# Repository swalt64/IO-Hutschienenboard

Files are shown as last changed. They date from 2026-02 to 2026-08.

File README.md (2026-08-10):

# IO-Hutschienenboard

ESP32-S3 basierter 12-Kanal-I/O-Hutschienencontroller mit Web-UI, OLED-Display und Android-App.

Aktuelle Firmware-Version: siehe `IO-Hutschienenboard_SRC/include/version.h` (wird bei jedem Upload automatisch hochgezählt).

## Hardware

Zwei-Platinen-Aufbau (Base Board + Top Board) mit ESP32-S3-WROOM-1 (N16R8, DUBEUYEW 44-pin DIL-Modul, Versorgung direkt über 3V3).

**Base Board:**
- **12× S0-Eingänge** — galvanisch getrennt (SL4U-1205 DC/DC), 6× ILD213T Optokoppler, 2× SN74HCT14DR Schmitt-Trigger; unterstützt DC-Kontakte und 8VAC-Erkennung
- **12× Relaisausgänge** — Panasonic DSP1A-L2-DC12V, **bistabil mit zwei Spulen**; angesteuert über **zwei** MCP23017 (0x21 = SET-Spulen, 0x20 = RESET-Spulen) → ULN2803A-Treiber → Ferritperlen → Relaisspulen; Impulsdauer 20 ms
- **Versorgung** — 12V-Eingang, AP62200WU-7 Buck-Wandler → 3V3p; SL4U-1205 isolierter DC/DC → I-5Vp für die Optokoppler
- **Peripherie-Reset** — GPIO2 (aktiv-low) auf alle drei MCP23017
- **Steckverbinder** — J200/J201 (S0-Eingänge + I-GND), J202 (externe Buchse, normalerweise unbestückt: I2C, GPIO13/14, Reset, 12V, 3V3p), J300–J302 (Relaiskontakte)

**Top Board (über 14-poligen Board-to-Board-Stecker P101 → P1):**
- **OLED-Display 128×64** — JMD0.96-1 (SSD1306) an I2C 0x3C
- **5 Navigationstasten** — ENTER, UP, DOWN, LEFT, RIGHT an MCP23017 0x22, GPA0–GPA4 (aktiv-low), Interrupt via INTA → GPIO13
- **3 Status-LEDs** — WLAN (rot), OUTPUT (gelb), RUN (grün) an MCP23017 0x22, GPB0–GPB2
- **Reset-Taster** auf dem EN-Pin des ESP32

**I2C-Adressen:** 0x20 (Relais RESET), 0x21 (Relais SET), 0x22 (Top Board), 0x3C (OLED). Bus: SDA = GPIO11, SCL = GPIO12, 100 kHz.

## Projektstruktur

- `IO-Hutschienenboard_SRC/` PlatformIO-Projektwurzel
  - `src/main.cpp` Kernanwendung: WiFi, AsyncWebServer, WebSocket, Relaissteuerung, Eingangs-Flankenerkennung, Auto-Off-Timer, Kanalnamen, Tastennavigation, NVS-Persistenz
  - `src/display.cpp` OLED-Ausgabe (Adafruit SSD1306), Namespace `display::`
  - `src/statusled.cpp` WS2812-RGB-LED-Muster (non-blocking)
  - `src/swtools.cpp` Debug-Logging mit Kategorien, ANSI-Farben, NTP-Zeitstempel
  - `include/pin_config.h` GPIO-Mapping, MCP-Adressen, Relaistabellen
  - `data/` LittleFS-Web-Assets: `index.html` (Bedienung), `config.html` (Konfiguration), `mapping.html` (Eingang→Ausgang), `status.html` (Systemstatus), PWA-Manifest + Service Worker
  - `boards/` eigenes PlatformIO-Board-Profil (`esp32-s3-devkitc-1-n16r8`)
  - `scripts/` Build-Hooks (Versions-Bump, OTA-Passwort einlesen)
- `AndroidApp/` native Android-App (siehe [AndroidApp/README.md](AndroidApp/README.md))
- `HARDWARE/PCB/` Altium-Designdaten (Base Board + Top Board)
- `DOKU/` Dokumentation und LTspice-Simulationen

## Funktionen

**Bedienung und Netzwerk**
- AP-Modus (`IO-Hutschiene`, 192.168.50.1) mit DHCP, parallel optionaler STA-Modus mit gespeicherten Zugangsdaten
- mDNS-Hostname `HS-IO` (`hs-io.local`)
- Web-UI mit WebSocket-Live-Updates, HTTP-Basic-Auth auf allen Seiten, der REST-API und dem WebSocket (Default `admin`/`admin`, in der UI änderbar)
- REST-API: `GET /api/state` (Gesamtzustand als JSON, inkl. `wifi_rssi`, `wifi_bssid`, `wifi_channel`), `GET /api/cmd` (`toggle`, `set`, `alloff`)
- Verbindet sich beim Start mit dem **stärksten** Access Point der SSID (relevant bei Repeater/Mesh mit gleicher SSID)
- PWA-fähig (Manifest + Service Worker), Android-App über dasselbe WebSocket-Protokoll

**Ausgänge**
- Auto-Off-Timer je Kanal mit Live-Countdown in Web-UI und Display
- Betriebsart je Ausgang: Toggle oder Taster
- Kanäle einzeln aktivierbar, frei sortierbar (Anzeigereihenfolge)
- Fernsteuer-Schutz je Ausgang: geschützte Kanäle schalten nur mit gesetztem `armed`-Flag
- „Alles aus" per Langdruck (2 s) auf einen Eingangs-Taster, über die Web-UI oder per langem Tastendruck in der App
- **Je Ausgang konfigurierbar, ob er bei „Alles aus" mitgeschaltet wird** — Spalte „Alles aus" in der Konfigurationsseite. Damit lassen sich Verbraucher wie eine Klimaanlage von der Sammelabschaltung ausnehmen; sie bleiben dann an, egal ob die Abschaltung vom Taster, der Web-UI oder der App kommt. Standard: alle Ausgänge werden mitgeschaltet.

**Eingänge**
- Flankenerkennung im `loop()`, gemapptes Relais wird geschaltet
- Betriebsart je Eingang: Toggle oder Taster
- DC- und AC-Erkennung (50 Hz Rechteck)
- Eigene Namen je Eingang

**Vor-Ort-Bedienung**
- OLED zeigt Kanalnummer, Name, EIN/AUS und Restlaufzeit
- UP/DOWN blättert Kanäle, ENTER schaltet, LEFT/RIGHT ändert die Restlaufzeit um ±1 min (temporär, nicht in NVS)
- WLAN-LED signalisiert Verbindungszustand und Signalqualität über die Blinkrate (Dauerlicht ab RSSI ≥ 50 %)

**Persistenz**
- NVS via Preferences, Namespace `io-config`: `ssid`, `pass`, `ui_user`, `ui_pass`, `ota_pass`, `mm*` (Eingangs-Zuordnung als Bitmaske), `auto*`, `outmode*`, `inmode*`, `ord*`, `ena*`, `prot*`, `name*`, `iname*`
- Konfiguration in der Web-UI exportier- und importierbar (`load_config`), Werksreset über `reset_io`
- **Reset per Taste beim Booten** (je 5 s halten, Fortschritt auf dem OLED, Loslassen bricht ab):
  - **ENTER** → Web- und OTA-Passwort zurück auf `admin`/`admin`
  - **DOWN** → E/A-Werkseinstellung: Zuordnungen, Timer und Namen zurücksetzen

**Update**
- ElegantOTA über die Web-UI (`/update`, passwortgeschützt)
- ArduinoOTA über PlatformIO-Environment `esp32s3-ota` (Port 3232)

## Build und Flash

Aus `IO-Hutschienenboard_SRC/` ausführen:

```powershell
& "C:\Users\stwal\.platformio\penv\Scripts\platformio.exe" run
& "C:\Users\stwal\.platformio\penv\Scripts\platformio.exe" run -t upload
& "C:\Users\stwal\.platformio\penv\Scripts\platformio.exe" run -t uploadfs
```

Nach Änderungen an `data/` muss `uploadfs` ausgeführt werden, sonst bleibt die alte Web-UI im Flash.

Die Plattform ist in `platformio.ini` fest auf `espressif32@6.12.0` gepinnt. Der Pin ist notwendig — mit dem neueren Arduino-Core 3.x kompilieren die WS2812-Bibliothek und die DHCP-Abfrage in `main.cpp` nicht mehr.

### OTA-Upload über WLAN

```powershell
& "C:\Users\stwal\.platformio\penv\Scripts\platformio.exe" run -e esp32s3-ota -t upload
```

Das OTA-Passwort wird aus `ota_pass.txt` gelesen (gitignored, Fallback `admin`). Nach einer Passwortänderung in der Web-UI muss diese Datei auf dem Entwicklungsrechner aktualisiert werden. Die Ziel-IP steht als `upload_port` in `platformio.ini`.

## Serieller Monitor

`platformio.ini` ist auf Rohausgabe konfiguriert: `monitor_speed = 115200`, `monitor_port = COM10`, `monitor_raw = yes`.

```powershell
& "C:\Users\stwal\.platformio\penv\Scripts\platformio.exe" device monitor -e esp32s3
```

## Bibliotheken

`ESP Async WebServer` (mathieucarbou) · `ArduinoJson` · `Adafruit MCP23017` · `Adafruit SSD1306` + `Adafruit GFX` · `Freenove WS2812 Lib for ESP32` · `ElegantOTA`

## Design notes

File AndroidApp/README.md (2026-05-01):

# HS-IO Android App

Native Android-App fuer das IO-Hutschienenboard.

## Funktionen

- Hauptansicht zeigt nur die 12 Ausgaenge.
- Links je Ausgang eine LED fuer den aktuellen Ausgangszustand.
- Rechts je Ausgang ein Button.
- Hochformat: einspaltige Liste.
- Querformat: zweispaltiges Raster.
- Verbindet sich per WebSocket mit `/ws` des ESP32.
- Verwendet dieselben Kommandos wie die Webseite:
  - Toggle-Ausgang: `{"cmd":"toggle","ch":n}`
  - Taster-Ausgang: `{"cmd":"set","ch":n,"val":true/false}`
  - langer Druck auf Toggle-Button: `{"cmd":"alloff"}`

## Build

In Android Studio den Ordner `AndroidApp` oeffnen und `app` bauen.

Standardverbindung:

- Host: `hs-io.local`
- Benutzer: `admin`
- Passwort: `admin`

Die Werte koennen in der App ueber das Menue `Einstellungen` geaendert werden.

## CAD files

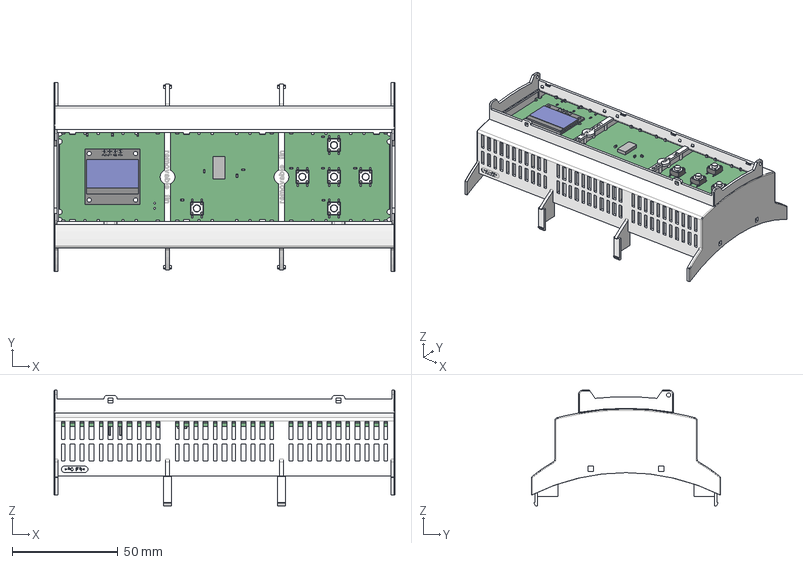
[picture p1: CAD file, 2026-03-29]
HARDWARE/PCB/3D-Objects/HS-IO TopBoard.step
161.6 x 89.7 x 54.9 mm
OLED-Disp
GPIO21HS-IO TopBoard
GPIO14HS-IO TopBoard
Extruded x 46
4301x20508x6 x 6
6100xx21121_PIN x 14
housing x 3
cover x 3
base-oa0 x 3
base x 3
Phoenix Geh㴳e BC 161,6 OT

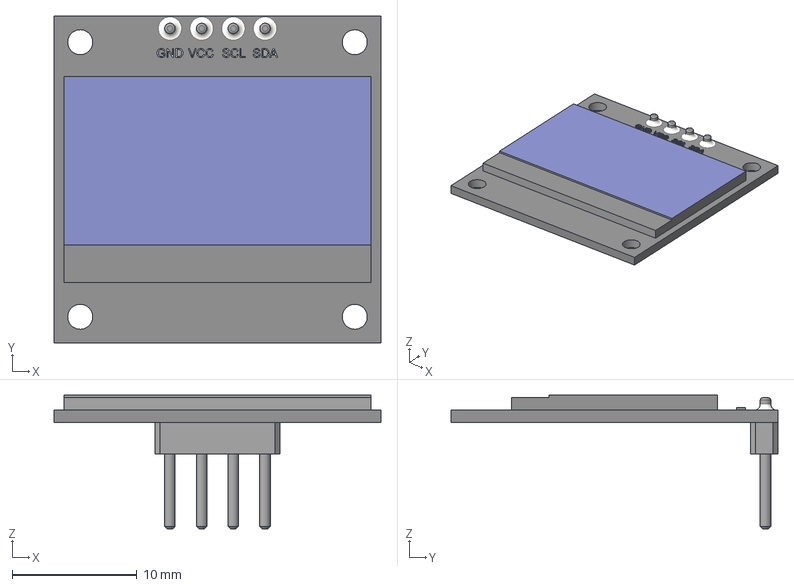
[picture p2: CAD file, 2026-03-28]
HARDWARE/PCB/3D-Objects/OLED-Disp.step
26.2 x 26.2 x 10.7 mm

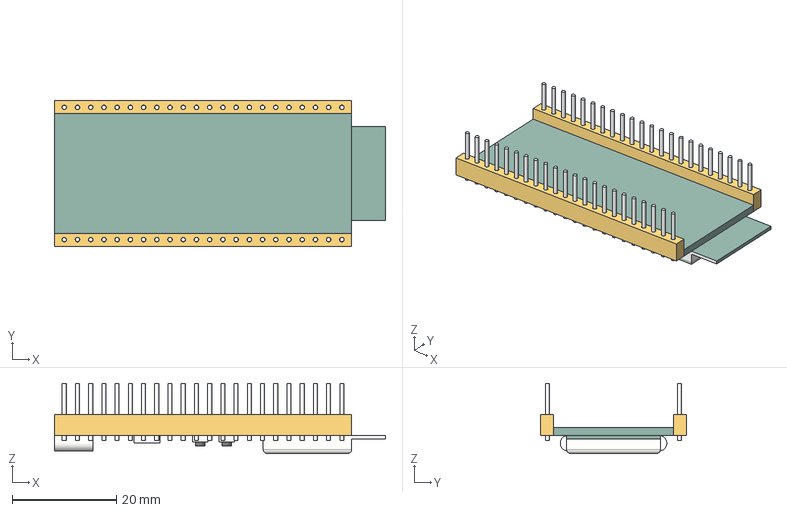
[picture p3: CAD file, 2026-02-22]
HARDWARE/PCB/3D-Objects/ESP32-S3-Board.step
63.6 x 28.1 x 13.5 mm

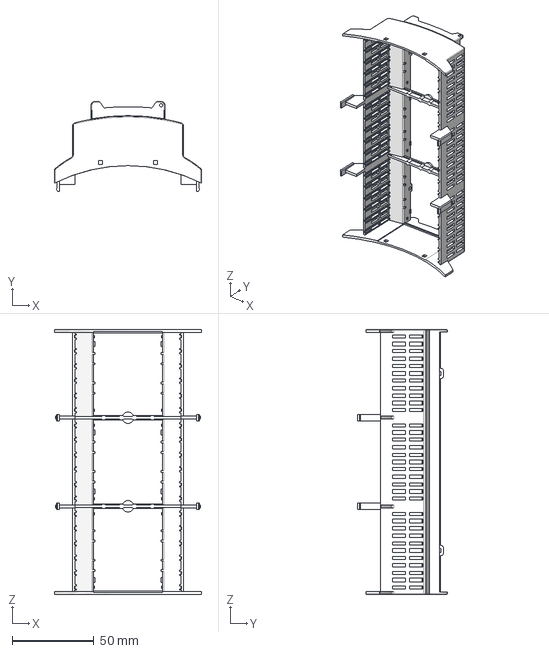
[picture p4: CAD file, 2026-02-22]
HARDWARE/PCB/3D-Objects/Phoenix Gehäuse BC 161,6 OT.step
89.7 x 54.9 x 161.6 mm

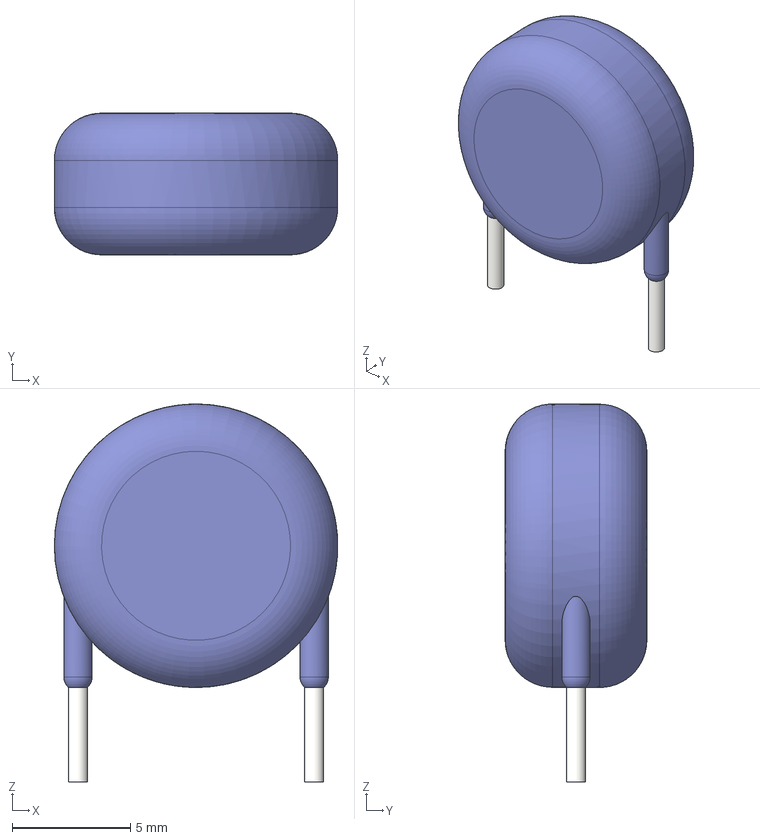
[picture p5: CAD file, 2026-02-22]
HARDWARE/PCB/3D-Objects/Y-Kondensator.step
12.0 x 6.00 x 16.0 mm

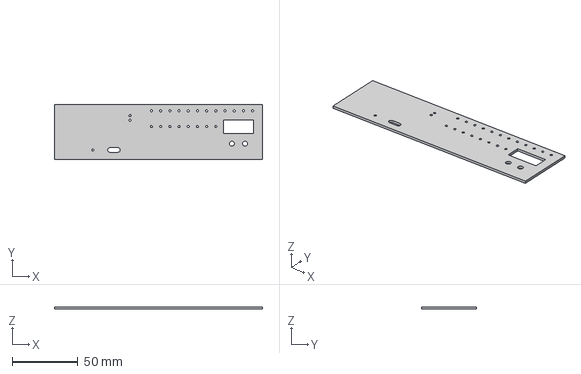
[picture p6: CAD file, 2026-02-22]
HARDWARE/PCB/3D-Objects/PQIO-Frontplatte.step
158.3 x 41.8 x 1.70 mm

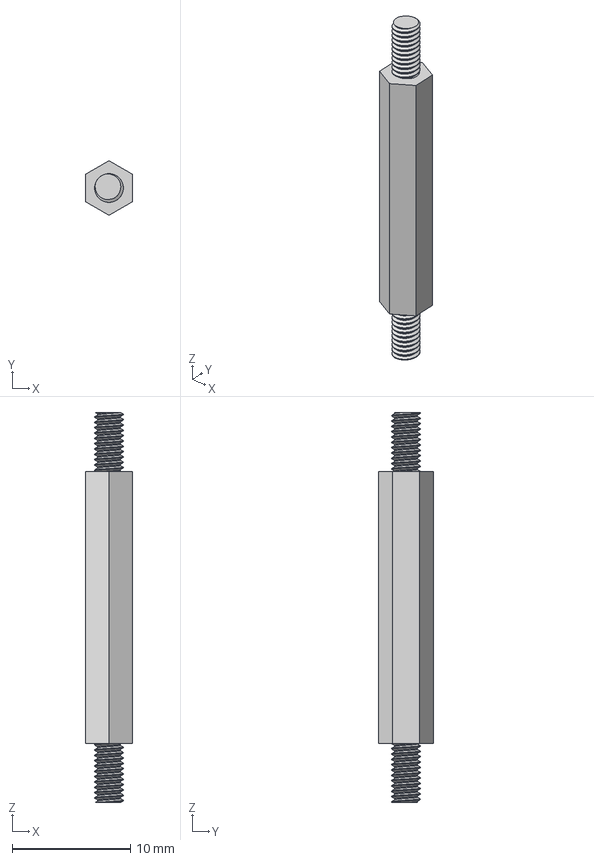
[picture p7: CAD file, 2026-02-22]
HARDWARE/PCB/3D-Objects/Distanzhalter M2.5 x 23 mm v1.step
4.00 x 4.62 x 33.0 mm

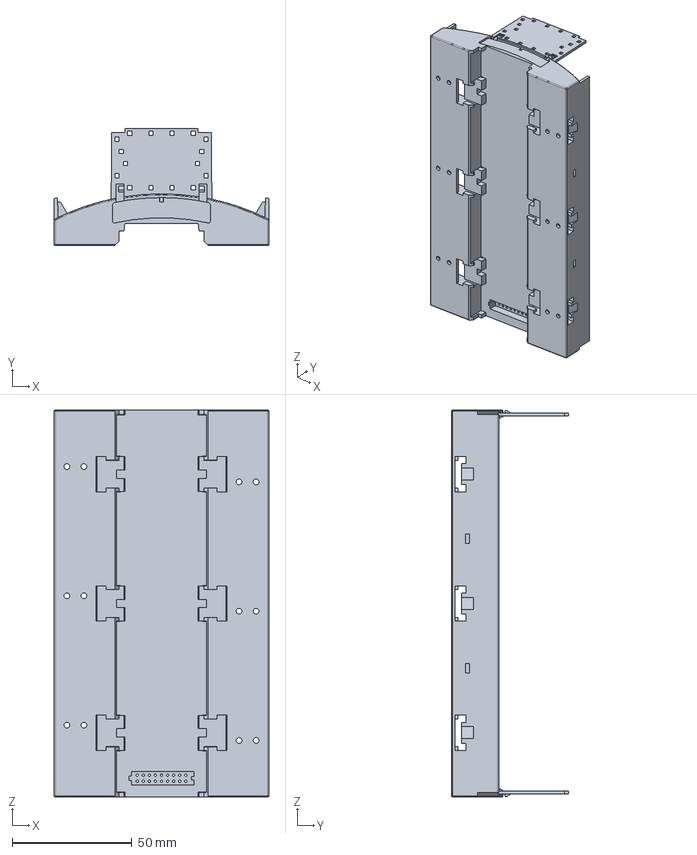
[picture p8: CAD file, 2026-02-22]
HARDWARE/PCB/3D-Objects/Phoenix Gehäuse BC 161,6 UT.step
89.7 x 48.9 x 161.6 mm

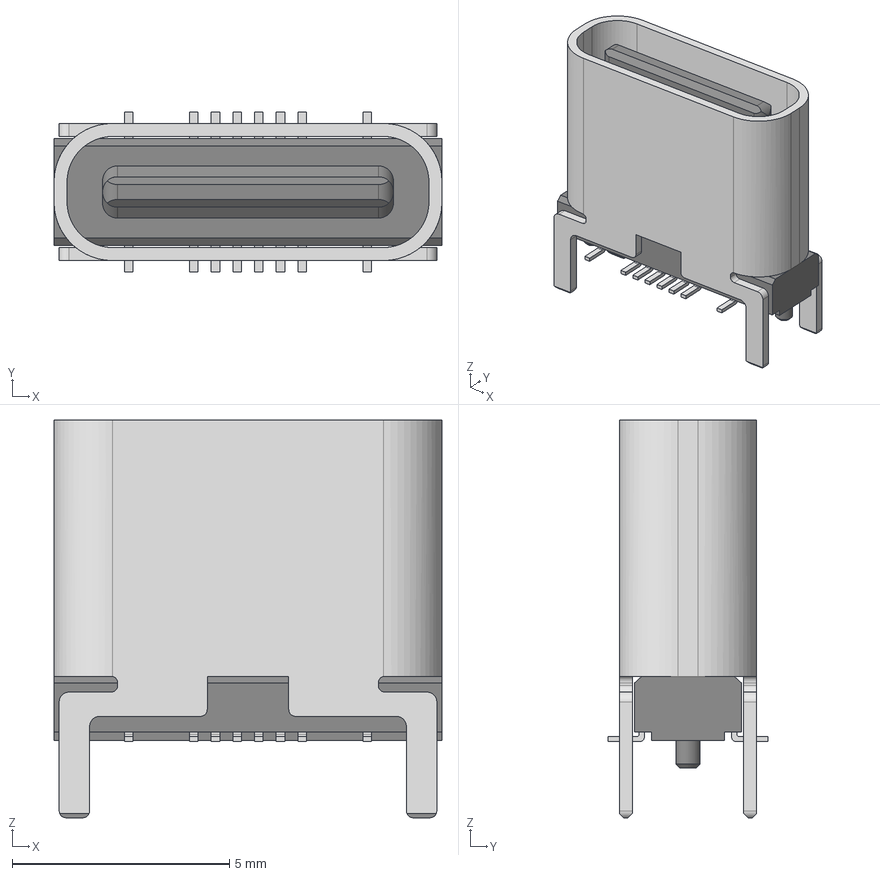
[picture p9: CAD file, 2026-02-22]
HARDWARE/PCB/3D-Objects/USB4145-03-0170-C.stp
8.94 x 3.69 x 9.16 mm

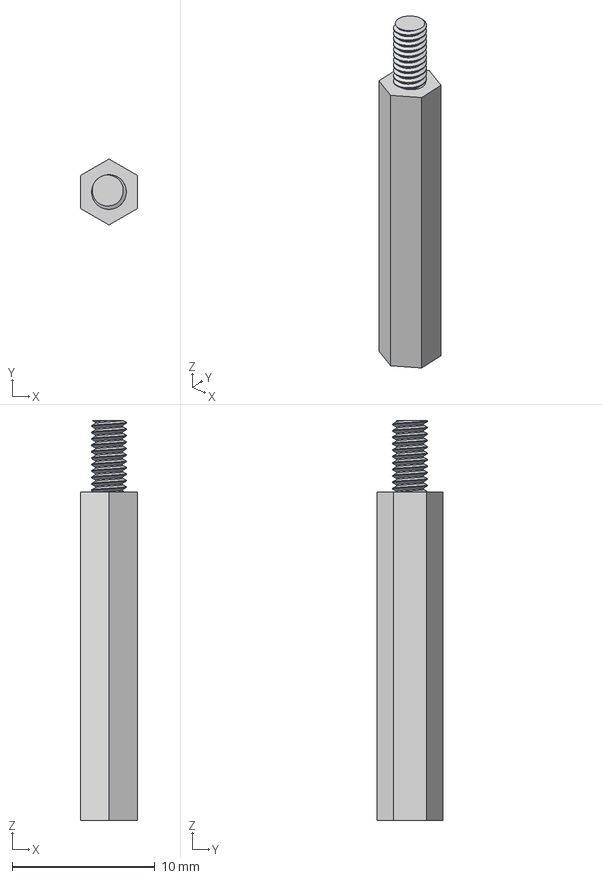
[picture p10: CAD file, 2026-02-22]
HARDWARE/PCB/3D-Objects/Distanzhalter M2.5 x 23 mm.step
4.00 x 4.62 x 28.0 mm

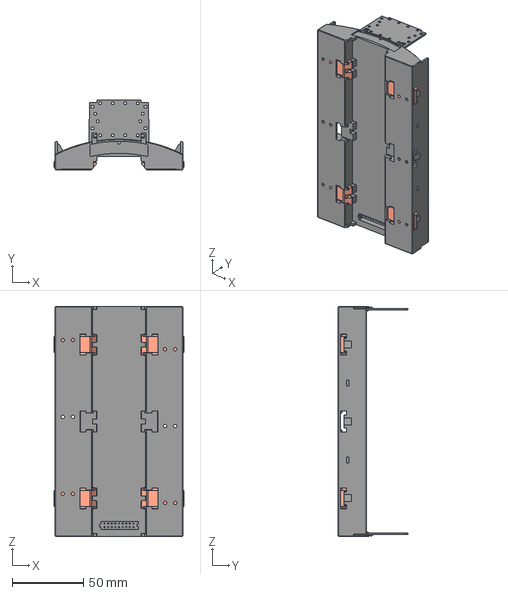
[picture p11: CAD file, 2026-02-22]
HARDWARE/PCB/3D-Objects/2278500.stp
91.0 x 48.9 x 161.6 mm

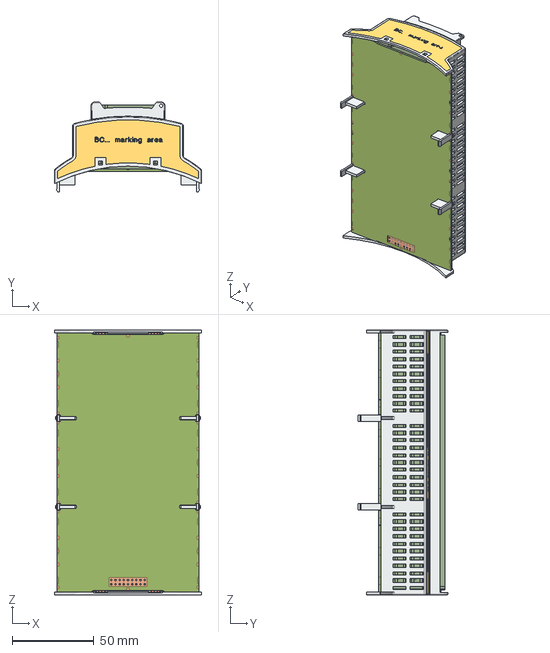
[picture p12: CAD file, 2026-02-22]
HARDWARE/PCB/3D-Objects/2278513.stp
89.7 x 54.9 x 161.6 mm

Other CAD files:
HARDWARE/PCB/3D-Objects/2278500_3D.dwg

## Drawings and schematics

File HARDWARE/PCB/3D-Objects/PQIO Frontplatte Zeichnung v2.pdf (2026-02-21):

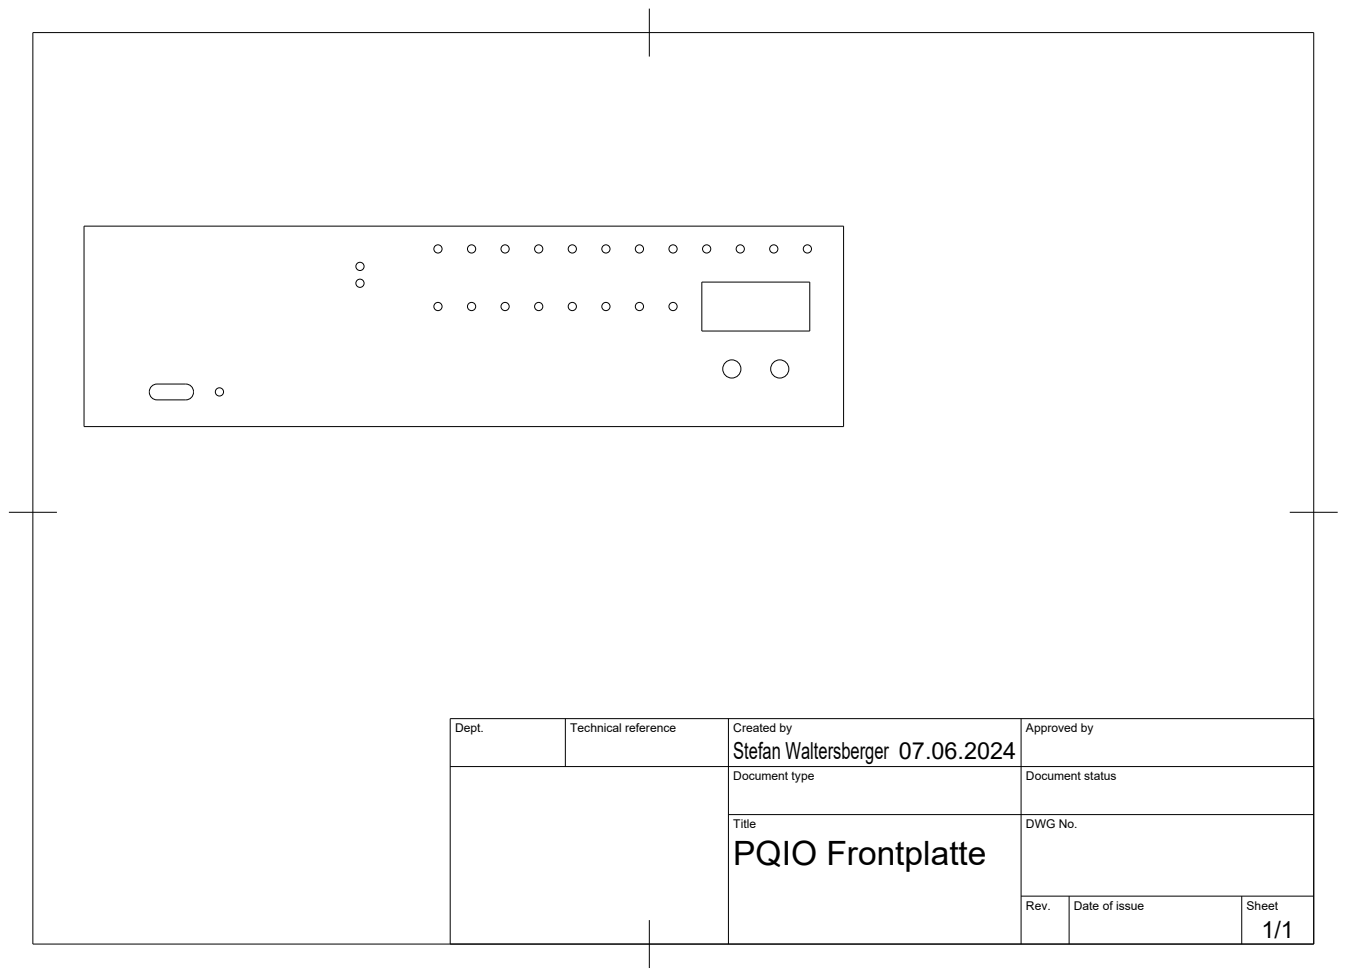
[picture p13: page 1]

Dept. | Technical reference | Created by Stefan Waltersberger 07.06.2024 | Approved by

Document type | Document status

Title PQIO Frontplatte | DWG No.

Rev. | Date of issue | Sheet 1/1

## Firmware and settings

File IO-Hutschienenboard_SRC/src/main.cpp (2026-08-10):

#include <Arduino.h>
#include <Wire.h>
#include <WiFi.h>
#include <esp_wifi.h>
#include <esp_netif.h>
#include <lwip/ip4_addr.h>
#include <dhcpserver/dhcpserver.h>
#include <ESPAsyncWebServer.h>
#include <LittleFS.h>
#include <ArduinoJson.h>
#include <Preferences.h>
#include <ArduinoOTA.h>
#include <ElegantOTA.h>
#include <ESPmDNS.h>
#if !SIMULATE_HW
#include <Adafruit_MCP23X17.h>
#endif
#include "pin_config.h"
#include "swtools.h"
#include "statusled.h"
#include "display.h"
#include "version.h"

using namespace dbg;

#ifndef OLED_HARDTEST
#define OLED_HARDTEST 0
#endif

#if OLED_HARDTEST
static bool probeI2CAddress(uint8_t addr);

static void oledCmd1(uint8_t addr, uint8_t cmd) {
    Wire.beginTransmission(addr);
    Wire.write(0x00);
    Wire.write(cmd);
    Wire.endTransmission();
}

static void oledCmd2(uint8_t addr, uint8_t cmd1, uint8_t cmd2) {
    Wire.beginTransmission(addr);
    Wire.write(0x00);
    Wire.write(cmd1);
    Wire.write(cmd2);
    Wire.endTransmission();
}

static void runOledHardTest() {
    const uint8_t addr = OLED_ADDR;

    dbg::info(CAT_SYSTEM, "=== OLED HARDTEST ===");
    dbg::info(CAT_SYSTEM, "OLED probe 0x3C: %s", probeI2CAddress(0x3C) ? "ACK" : "kein ACK");
    dbg::info(CAT_SYSTEM, "OLED probe 0x3D: %s", probeI2CAddress(0x3D) ? "ACK" : "kein ACK");

    if (!probeI2CAddress(addr)) {
        dbg::warn(CAT_SYSTEM, "OLED antwortet nicht auf 0x%02X", addr);
        return;
    }

    oledCmd1(addr, 0xAE);
    oledCmd2(addr, 0xD5, 0x80);
    oledCmd2(addr, 0xA8, 0x3F);
    oledCmd2(addr, 0xD3, 0x00);
    oledCmd1(addr, 0x40);
    oledCmd2(addr, 0x8D, 0x14);
    oledCmd2(addr, 0x20, 0x00);
    oledCmd1(addr, 0xA1);
    oledCmd1(addr, 0xC8);
    oledCmd2(addr, 0xDA, 0x12);
    oledCmd2(addr, 0x81, 0xCF);
    oledCmd2(addr, 0xD9, 0xF1);
    oledCmd2(addr, 0xDB, 0x40);
    oledCmd1(addr, 0xA4);
    oledCmd1(addr, 0xA6);
    oledCmd1(addr, 0xAF);
    delay(100);

    oledCmd1(addr, 0xA5);
    dbg::warn(CAT_SYSTEM, "OLED Hardtest aktiv: ALL PIXELS ON auf 0x%02X", addr);
}
#endif

// ============================================================
// WiFi Configuration - AP mode for initial setup
// ============================================================
const char* AP_SSID = "IO-Hutschiene";
const char* AP_PASS = "12345678";   // HINWEIS: Standard-AP-Passwort – für Produktiveinsatz ändern
const IPAddress AP_IP(192, 168, 50, 1);
const IPAddress AP_GATEWAY(192, 168, 50, 1);
const IPAddress AP_SUBNET(255, 255, 255, 0);
const bool ENABLE_DHCP_DIAG = false;

String sta_ssid = "";
String sta_pass = "";
String ui_user  = "admin";   // Produktiveinsatz: in Web-UI ändern
String ui_pass  = "admin";   // Produktiveinsatz: in Web-UI ändern
String ota_pass = "admin";   // Produktiveinsatz: muss mit --auth in platformio.ini übereinstimmen

// ============================================================
// Global State
// ============================================================
AsyncWebServer server(80);
AsyncWebSocket ws("/ws");
Preferences prefs;

static AsyncCallbackWebHandler* g_apiHandler    = nullptr;
static AsyncCallbackWebHandler* g_cmdHandler    = nullptr;
static AsyncStaticWebHandler*   g_staticHandler = nullptr;

static void applyWebAuth() {
    if (g_apiHandler)    g_apiHandler->setAuthentication(ui_user.c_str(), ui_pass.c_str());
    if (g_cmdHandler)    g_cmdHandler->setAuthentication(ui_user.c_str(), ui_pass.c_str());
    if (g_staticHandler) g_staticHandler->setAuthentication(ui_user.c_str(), ui_pass.c_str());
    ws.setAuthentication(ui_user.c_str(), ui_pass.c_str());
    ElegantOTA.setAuth(ui_user.c_str(), ui_pass.c_str());
}

#if !SIMULATE_HW
Adafruit_MCP23X17 mcp[2];
Adafruit_MCP23X17 mcpTop;
#endif
bool mcpReady[2]  = {false, false};
bool mcpTopReady  = false;

volatile bool topBtnFlag = false;
volatile bool pendingAllOff = false;
void IRAM_ATTR topBtnISR() { topBtnFlag = true; }

bool   relayState[NUM_CHANNELS] = {false};
bool   inputState[NUM_CHANNELS] = {false};
time_t lastInputTime[NUM_CHANNELS]  = {0};  // Unix-Timestamp letzte Betätigung
time_t lastOutputTime[NUM_CHANNELS] = {0};  // Unix-Timestamp letzte Relais-Aktion

unsigned long inputLastEdgeMs[NUM_CHANNELS]  = {};
bool          inputRawPrev[NUM_CHANNELS]     = {};
unsigned long pressStartMs[NUM_CHANNELS]     = {};
bool          signalActivePrev[NUM_CHANNELS] = {};
bool          longPressFired[NUM_CHANNELS]   = {};

uint16_t inputMapping[NUM_CHANNELS]; // Bitmask: Bit j = Eingang steuert Ausgang j
uint8_t  outputMode[NUM_CHANNELS]  = {0}; // 0=Toggle, 1=Taster
uint8_t  inputMode[NUM_CHANNELS]   = {0}; // 0=Toggle, 1=Taster

uint32_t autoOffSeconds[NUM_CHANNELS] = {0};
unsigned long relayOnTimestamp[NUM_CHANNELS] = {0};
int32_t tempTimeAdjustMs[NUM_CHANNELS] = {0};
unsigned long timerFreezeStart[NUM_CHANNELS]  = {0};  // Freeze-Beginn (0=inaktiv)
unsigned long timerFreezeExpiry[NUM_CHANNELS] = {0};  // Freeze-Ablauf

static inline unsigned long getTimerEffectiveNow(uint8_t ch) {
    return (timerFreezeStart[ch] > 0) ? timerFreezeStart[ch] : millis();
}

char channelNames[NUM_CHANNELS][CH_NAME_MAX_LEN + 1];
char inputNames[NUM_CHANNELS][CH_NAME_MAX_LEN + 1];
uint8_t displayChannel = 0;

uint8_t outDisplayOrder[NUM_CHANNELS] = {0,1,2,3,4,5,6,7,8,9,10,11};
bool    outChEnabled[NUM_CHANNELS]    = {true,true,true,true,true,true,true,true,true,true,true,true};
bool    outRemoteProtected[NUM_CHANNELS] = {};
// true = Ausgang wird bei "Alle Ausgaenge AUS" mit ausgeschaltet (Eingangs-Langdruck,
// Web-UI, App). false = Ausgang bleibt unberuehrt, z.B. Klimaanlage.
bool    outAllOffEnabled[NUM_CHANNELS] = {true,true,true,true,true,true,true,true,true,true,true,true};

uint32_t getRemainingAutoOffSeconds(uint8_t ch, unsigned long nowMs) {
    if (ch >= NUM_CHANNELS) return 0;
    if (!relayState[ch]) return 0;
    if (relayOnTimestamp[ch] == 0) return 0;

    const int64_t totalMs = (int64_t)autoOffSeconds[ch] * 1000LL + tempTimeAdjustMs[ch];
    if (totalMs <= 0) return 0;

    const unsigned long elapsedMs = nowMs - relayOnTimestamp[ch];
    if (elapsedMs >= (unsigned long)totalMs) return 0;

    const unsigned long remainingMs = (unsigned long)totalMs - elapsedMs;
    return (remainingMs + 999UL) / 1000UL;
}

static int32_t btnStepMs(uint32_t remainSecs) {
    if (remainSecs <=   900) return    60000;  // bis 15 min  →  1 min
    if (remainSecs <=  3600) return   300000;  // bis 1h      →  5 min
    if (remainSecs <=  7200) return   600000;  // bis 2h      → 10 min
    if (remainSecs <= 21600) return  1800000;  // bis 6h      → 30 min
    if (remainSecs <= 86400) return  3600000;  // bis 24h     →  1 h
    if (remainSecs <= 172800) return 21600000; // bis 48h     →  6 h
    return 21600000;                           // über 48h    →  6 h
}

// ============================================================
// Display-Aktualisierung für den aktuell angezeigten Kanal
// ============================================================
void updateDisplay() {
    uint8_t ch = displayChannel;
    uint16_t mask = 0;
    for (uint8_t i = 0; i < NUM_CHANNELS; i++)
        if (relayState[i]) mask |= (1u << i);
    display::show(ch, channelNames[ch], relayState[ch],
                  getRemainingAutoOffSeconds(ch, getTimerEffectiveNow(ch)),
                  autoOffSeconds[ch] > 0 || tempTimeAdjustMs[ch] > 0,
                  mask);
}

// ============================================================
// Top Board: Status-LEDs aktualisieren (GPB0-2, aktiv-low)
// ============================================================
void updateTopLeds() {
#if !SIMULATE_HW
    if (!mcpTopReady) return;

    bool staConnected = (WiFi.status() == WL_CONNECTED);
    bool anyRelayOn = false;
    for (uint8_t i = 0; i < NUM_CHANNELS; i++) {
        if (relayState[i]) { anyRelayOn = true; break; }
    }
    bool systemReady = (mcpReady[0] && mcpReady[1]);

    // WLAN-LED (2s-Periode):
    //   kein STA          → aus
    //   STA, keine IP     → 10/90 (200ms an, 1800ms aus)
    //   IP, RSSI < 50%    → 80/20 (1600ms an,  400ms aus)
    //   IP, RSSI >= 50%   → Dauerlicht
    bool hasIP = staConnected && (WiFi.localIP() != IPAddress(0, 0, 0, 0));
    bool wlanOn = false;
    if (hasIP) {
        int pct = min(100, max(0, 2 * (WiFi.RSSI() + 100)));
        wlanOn = (pct >= 50) ? true : ((millis() % 2000) < 1600);
    } else if (staConnected) {
        wlanOn = (millis() % 2000) < 200;
    }
    mcpTop.digitalWrite(LED_WLAN_PIN, wlanOn ? LOW : HIGH);
    mcpTop.digitalWrite(LED_OUTPUT_PIN, anyRelayOn ? LOW : HIGH);
    // RUN-LED: 2s-Blinker (1s an, 1s aus) wenn System bereit
    if (systemReady) {
        bool runOn = ((millis() / 1000) % 2) == 0;
        mcpTop.digitalWrite(LED_RUN_PIN, runOn ? LOW : HIGH);
    } else {
        mcpTop.digitalWrite(LED_RUN_PIN, HIGH);  // aus
    }
#endif
}

void saveConfig();  // forward declaration

// handleButton() ist nach onWebSocketEvent() definiert (benötigt sendState etc.)
void handleButton(uint8_t btn);

// ============================================================
// Helper: determine correct LED state based on system status
// ============================================================
void updateLedState() {
#if !SIMULATE_HW
    if (!mcpReady[0] && !mcpReady[1]) {
        statusled::setState(statusled::ST_MCP_ERROR);
        return;
    }
#endif

    bool anyRelayOn = false;
    for (uint8_t i = 0; i < NUM_CHANNELS; i++) {
        if (relayState[i]) { anyRelayOn = true; break; }
    }

    bool wsClients = ws.count() > 0;

    if (anyRelayOn) {
        statusled::setState(statusled::ST_RELAY_ACTIVE);
    } else if (wsClients) {
        statusled::setState(statusled::ST_WS_CLIENT);
    } else if (WiFi.status() == WL_CONNECTED && dbg::isTimeSynced()) {
        statusled::setState(statusled::ST_READY);
    } else if (WiFi.status() == WL_CONNECTED) {
        statusled::setState(statusled::ST_WIFI_NO_NTP);
    } else {
        statusled::setState(statusled::ST_AP_ONLY);
    }

    updateTopLeds();
}

// ============================================================
// MCP23017 Init
// ============================================================
// I2C-Bus-Recovery: SDA nach Soft-Reset stuck → 9 SCL-Pulse + STOP-Condition
static void i2cBusRecover() {
    pinMode(I2C_SCL_PIN, OUTPUT);
    pinMode(I2C_SDA_PIN, OUTPUT);
    digitalWrite(I2C_SDA_PIN, HIGH);
    for (int i = 0; i < 9; i++) {
        digitalWrite(I2C_SCL_PIN, HIGH); delayMicroseconds(5);
        digitalWrite(I2C_SCL_PIN, LOW);  delayMicroseconds(5);
    }
    // STOP condition: SDA LOW → SCL HIGH → SDA HIGH
    digitalWrite(I2C_SDA_PIN, LOW);  delayMicroseconds(5);
    digitalWrite(I2C_SCL_PIN, HIGH); delayMicroseconds(5);
    digitalWrite(I2C_SDA_PIN, HIGH); delayMicroseconds(5);
    // Pins auf INPUT zurück damit Wire sie übernehmen kann
    pinMode(I2C_SCL_PIN, INPUT);
    pinMode(I2C_SDA_PIN, INPUT);
}

static bool probeI2CAddress(uint8_t addr) {
    Wire.beginTransmission(addr);
    return Wire.endTransmission() == 0;
}
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
void loop() {
#if OLED_HARDTEST
    delay(1000);
    return;
#endif

    ArduinoOTA.handle();
    ElegantOTA.loop();

    if (pendingAllOff) {
        pendingAllOff = false;
        allOutputsOff("Alles-Aus-Kommando");
        sendState();
    }

    ws.cleanupClients();
    statusled::update();

    // Top Board: Taster via Polling (50ms-Takt) + INTA-Interrupt als Trigger
#if !SIMULATE_HW
    if (mcpTopReady) {
        static unsigned long lastPollMs  = 0;
        static uint8_t       lastGpa     = 0xFF;
        static uint8_t       heldBtn     = 0xFF;   // aktuell gehaltene Taste
        static unsigned long heldSince   = 0;       // wann gedrückt
        static unsigned long lastRepeatMs = 0;      // letzter Repeat-Feuerzeitpunkt
        static const uint32_t REPEAT_DELAY_MS  = 600;
        static const uint32_t REPEAT_PERIOD_MS = 150;

        unsigned long nowBtn = millis();
        if (topBtnFlag || (nowBtn - lastPollMs >= 50)) {
            topBtnFlag = false;
            lastPollMs = nowBtn;
            uint16_t gpioVal = mcpTop.readGPIOAB();
            uint8_t  gpa     = gpioVal & 0xFF;
            uint8_t  held    = (~gpa) & 0x1F;   // aktuell gedrückte Bits (alle 5 Tasten)
            uint8_t  pressed = (~gpa) & lastGpa; // nur neue Flanken
            lastGpa = gpa;

            // Flanken: sofort auslösen
            if (pressed & (1 << BTN_ENTER)) handleButton(BTN_ENTER);
            if (pressed & (1 << BTN_UP))    handleButton(BTN_UP);
            if (pressed & (1 << BTN_DOWN))  handleButton(BTN_DOWN);
            if (pressed & (1 << BTN_LEFT))  { handleButton(BTN_LEFT);  heldBtn = BTN_LEFT;  heldSince = nowBtn; lastRepeatMs = nowBtn; }
            if (pressed & (1 << BTN_RIGHT)) { handleButton(BTN_RIGHT); heldBtn = BTN_RIGHT; heldSince = nowBtn; lastRepeatMs = nowBtn; }

            // Auto-Repeat für LEFT / RIGHT
            if (heldBtn != 0xFF) {
                if (held & (1 << heldBtn)) {
                    // Taste noch gehalten
                    if ((nowBtn - heldSince >= REPEAT_DELAY_MS) &&
                        (nowBtn - lastRepeatMs >= REPEAT_PERIOD_MS)) {
                        lastRepeatMs = nowBtn;
                        handleButton(heldBtn);
                    }
                } else {
                    heldBtn = 0xFF; // losgelassen
                }
            }
        }
    }
#endif

    bool stateChanged = false;

    // Eingangserkennung: einheitliche Signal-Erkennung für DC und 8VAC (50Hz)
    // signalActive = HIGH (DC) ODER letzte Flanke < 30ms her (AC-Halbwellen-Lücke)
    // Gemeinsame Press-State-Machine für Toggle- und Taster-Modus:
    //   Steigende Flanke  → pressStartMs merken, longPressFired löschen
    //   Während aktiv     → nach 2s alle Ausgänge AUS (Langdruck), einmalig
    //   Fallende Flanke   → Toggle: OR-Toggle; Taster: Ausgänge AUS (nur wenn kein Langdruck)
    static const uint32_t IN_ACTIVE_HOLD_MS = 30;    // Halbwellen-Lücke AC
    static const uint32_t IN_LONGPRESS_MS   = 2000;  // Langdruck-Schwelle
    unsigned long nowIn = millis();
    for (uint8_t i = 0; i < NUM_CHANNELS; i++) {
        bool raw  = digitalRead(INPUT_PINS[i]);
        bool edge = (raw != inputRawPrev[i]);
        inputRawPrev[i] = raw;

        if (edge) inputLastEdgeMs[i] = nowIn;

        // GPIO ist aktiv-LOW (Schmitt-Inverter invertiert Optokoppler-Ausgang)
        bool signalActive = !raw || (nowIn - inputLastEdgeMs[i] < IN_ACTIVE_HOLD_MS);
        bool risingEdge   =  signalActive && !signalActivePrev[i];
        bool fallingEdge  = !signalActive &&  signalActivePrev[i];
        signalActivePrev[i] = signalActive;

        // UI: Eingangs-LED folgt signalActive
        if (signalActive != inputState[i]) {
            inputState[i] = signalActive;
            stateChanged  = true;
        }

        if (risingEdge) {
            pressStartMs[i]   = nowIn;
            longPressFired[i] = false;
            lastInputTime[i]  = time(nullptr);
            if (inputMode[i] == 1) {
                // Eingangs-Tastermodus: alle gemappten Ausgänge folgen dem Eingang.
                for (uint8_t j = 0; j < NUM_CHANNELS; j++) {
                    if (inputMapping[i] & (1u << j)) setRelay(j, true);
                }
                stateChanged = true;
            } else {
                // Eingangs-Togglemodus: Ausgänge im Tastermodus folgen trotzdem dem Eingang.
                for (uint8_t j = 0; j < NUM_CHANNELS; j++) {
                    if ((inputMapping[i] & (1u << j)) && outputMode[j] == 1) {
                        setRelay(j, true);
                    }
                }
                stateChanged = true;
            }
        }

        // Langdruck nur im Eingangs-Togglemodus: Taster-Eingaenge duerfen
        // gehalten werden, ohne global alle Ausgaenge auszuschalten.
        if (inputMode[i] == 0 && signalActive && !longPressFired[i] &&
            (nowIn - pressStartMs[i] >= IN_LONGPRESS_MS)) {
            char reason[32];
            snprintf(reason, sizeof(reason), "Eingang %d Langdruck", i + 1);
            allOutputsOff(reason);
            longPressFired[i] = true;
            stateChanged = true;
        }

        if (fallingEdge && !longPressFired[i]) {
            if (inputMode[i] == 1) {
                // Eingangs-Tastermodus: alle gemappten Ausgänge AUS.
                for (uint8_t j = 0; j < NUM_CHANNELS; j++) {
                    if (inputMapping[i] & (1u << j)) setRelay(j, false);
                }
            } else {
                // Ausgänge im Tastermodus AUS; nur Toggle-Ausgänge werden getoggelt.
                for (uint8_t j = 0; j < NUM_CHANNELS; j++) {
                    if ((inputMapping[i] & (1u << j)) && outputMode[j] == 1) {
                        setRelay(j, false);
                    }
                }

                // Toggle: OR-Logik über Toggle-Ausgänge (irgendeiner AN → alle AUS, sonst alle AN)
                if (inputMapping[i]) {
                    bool anyOn = false;
                    for (uint8_t j = 0; j < NUM_CHANNELS; j++) {
                        if ((inputMapping[i] & (1u << j)) && outputMode[j] == 0 && relayState[j]) {
                            anyOn = true;
                            break;
                        }
                    }
                    bool newState = !anyOn;
                    dbg::info(CAT_INPUT, "Eingang %d Toggle → %s", i+1, newState ? "EIN" : "AUS");
                    for (uint8_t j = 0; j < NUM_CHANNELS; j++) {
                        if ((inputMapping[i] & (1u << j)) && outputMode[j] == 0) {
                            setRelay(j, newState, !newState);
                        }
                    }
                }
            }
            stateChanged = true;
        }
    }

    // Timer-Freeze Ablauf prüfen → relayOnTimestamp verschieben
    unsigned long now = millis();
    for (uint8_t i = 0; i < NUM_CHANNELS; i++) {
        if (timerFreezeStart[i] > 0 && (long)(now - timerFreezeExpiry[i]) >= 0) {
            relayOnTimestamp[i] += timerFreezeExpiry[i] - timerFreezeStart[i];
            timerFreezeStart[i]  = 0;
            timerFreezeExpiry[i] = 0;
            stateChanged = true;
        }
    }

    // Auto-off timer check
    for (uint8_t i = 0; i < NUM_CHANNELS; i++) {
        if (relayState[i] && (autoOffSeconds[i] > 0 || tempTimeAdjustMs[i] > 0) && relayOnTimestamp[i] > 0) {
            if (getRemainingAutoOffSeconds(i, getTimerEffectiveNow(i)) == 0) {
                dbg::info(CAT_TIMER, "Auto-Aus: Relais %d", i + 1);
                setRelay(i, false);
                stateChanged = true;
            }
        }
    }

    // RUN-LED Blinker + Display-Scroll: alle 250ms aktualisieren
    static unsigned long lastLedTick = 0;
    if (now - lastLedTick >= 250) {
        lastLedTick = now;
        updateTopLeds();
        display::tick(now);
    }

    // Display jede Sekunde aktualisieren (Countdown)
    static unsigned long lastDisp = 0;
    if (now - lastDisp >= 1000) {
        lastDisp = now;
        updateDisplay();
    }

    // Update LED when NTP syncs
    static bool lastNtpState = false;
    if (dbg::isTimeSynced() && !lastNtpState) {
        dbg::info(CAT_NTP, "NTP synchronisiert: %s", dbg::getTimestamp().c_str());
        updateLedState();
        lastNtpState = true;
    }

    // Periodische AP-Station-Ãœberwachung (alle 5 Sekunden)
    static unsigned long lastStaCheck = 0;
    static uint8_t lastStaCount = 255;
    if (now - lastStaCheck >= 5000) {
        lastStaCheck = now;
        uint8_t staCount = WiFi.softAPgetStationNum();
        if (staCount != lastStaCount) {
            dbg::info(CAT_WIFI, "AP Stationen: %d (vorher: %d)", staCount, lastStaCount);
            lastStaCount = staCount;
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

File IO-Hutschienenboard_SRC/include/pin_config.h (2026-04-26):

#pragma once
#include <stdint.h>

// ============================================================
// Pin Configuration for IO-Hutschienenboard
// ESP32-S3-WROOM-1 (DUBEUYEW)
// ============================================================
//
// Architecture:
//   12 AC Inputs  -> Optocoupler -> ESP32 GPIO (direct, fast edge detection)
//   12 Bistable Relays -> 2x MCP23017 via I2C
//
// MCP23017 address scheme:
//   0x20 (A2=0, A1=0, A0=0) : Relay RESET coils
//   0x21 (A2=0, A1=0, A0=1) : Relay SET coils
//   0x22 (A2=0, A1=1, A0=0) : Top board buttons and LEDs
//

// --- I2C Bus ---
static const uint8_t I2C_SDA_PIN = 11;
static const uint8_t I2C_SCL_PIN = 12;

// --- MCP23017 I2C addresses ---
static const uint8_t MCP_ADDR_SET      = 0x21;
static const uint8_t MCP_ADDR_RESET    = 0x20;
static const uint8_t MCP_ADDR_TOPBOARD = 0x22;

// --- Top Board interrupt ---
static const uint8_t MCP_INT_PIN = 13;

// --- Top Board buttons (active low) ---
static const uint8_t BTN_ENTER = 0;
static const uint8_t BTN_UP    = 1;
static const uint8_t BTN_DOWN  = 2;
static const uint8_t BTN_LEFT  = 3;
static const uint8_t BTN_RIGHT = 4;

// --- Top Board status LEDs (active low) ---
static const uint8_t LED_WLAN_PIN   =  8;
static const uint8_t LED_OUTPUT_PIN =  9;
static const uint8_t LED_RUN_PIN    = 10;

// --- 12 digital inputs ---
static const uint8_t INPUT_PINS[12] = {
    4,
    5,
    6,
    7,
    15,
    16,
    17,
    18,
    8,
    3,
    9,
    10,
};

// --- Relay pin mapping ---
static const uint8_t RELAY_PINS[12] = {
    0,
    1,
    2,
    3,
    4,
    5,
    6,
    7,
    8,
    9,
    10,
    11,
};

// MCP array indices
static const uint8_t MCP_SET   = 0;
static const uint8_t MCP_RESET = 1;

// Bistable relay pulse
static const uint16_t RELAY_PULSE_MS = 20;

// Number of channels
static const uint8_t NUM_CHANNELS = 12;

// Peripheral reset (active low, MCP23017 + OLED)
static const uint8_t RESET_PERIPHERIE_PIN = 2;

// OLED display
static const uint8_t OLED_ADDR       = 0x3C;
static const uint8_t CH_NAME_MAX_LEN = 60;

// Free ESP32 GPIOs:
// GPIO0, 1, 2, 14, 21, 35, 36, 37, 38, 39, 40, 41, 42, 45, 46, 47, 48

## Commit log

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2026-02-21 Add CLAUDE.md and update README with verified hardware documentation
    Document the new 12-channel hardware design based on Altium schematic
    and netlist: S0 inputs (ILD213T + SN74HCT14DR), monostable relay
    outputs (MCP23017 + ULN2803A + DSP1a-DC12V), isolated power supply,
    ESP32-S3 GPIO allocation, and top board connector pinout.
2026-02-21 Add hardware design files and Claude Code settings
    Include Altium PCB design (base board schematics, 3D models, netlist),
    Claude Code local settings, and root .gitignore to exclude Altium
    backup history.
    [2278500.stp, 2278500_3D.dwg, Distanzhalter M2.5 x 23 mm v1.step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]
2026-02-22 fix: ESP32-S3 Altium-Symbol korrigiert, LOG-Dateien aus Git entfernt
    - GPIO8: ADC-Kanal korrigiert von ADC2_8 auf ADC1_7
    - GPIO19/GPIO20: USB D+ und D− Zuweisung getauscht (GPIO19=USB_D−, GPIO20=USB_D+)
    - .gitignore: *.LOG und "Project Logs for */" Ordner hinzugefügt
    - 23 bereits getrackte Altium-LOG-Dateien aus Git-Index entfernt
    - ESP32-S3-Board.step 3D-Modell hinzugefügt
    [2278500.stp, 2278513.stp, Distanzhalter M2.5 x 23 mm v1.step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]
2026-02-22 feat: BringToCursor Altium-Script für PCB hinzugefügt
    - DelphiScript zur schnellen Bauteilplatzierung per Designator-Eingabe
    - Bauteil kommt zum Cursor statt Cursor zum Bauteil
    - Script Project (.PrjScr) für globale Installation vorbereitet
    - Installation: Scripting System → Global Projects → Install BringToCursor.PrjScr
    [HS-IO Baseboard.PrjPcb, HS-IO ESP32.SchDoc, HS-IO Inputs.SchDoc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]
2026-02-22 refactor: BringToCursor-Script entfernt
    Altium hat bereits eine native Funktion "Move Component" die das
    Bauteil zum Cursor holt - Script wird nicht benötigt.
2026-02-22 docs: Altium Designer Workflows in CLAUDE.md dokumentiert
    - Move Component to Cursor Workflow für PCB-Platzierung
    - ESP32-S3 Pinout-Verifikation und häufige Fehler
    - JTAG-, ADC-, USB-Zuordnungen dokumentiert
2026-03-02 refactor: I2C-Adressschema auf SET/RESET-MCPs umgestellt
    Relay MCP23017 Adressen neu:
    - 0x20 (MCP_ADDR_SET): alle 12 SET-Spulen (GPA0-7 + GPB0-3)
    - 0x21 (MCP_ADDR_RESET): alle 12 RESET-Spulen (GPA0-7 + GPB0-3)
    - 0x22: Top Board LEDs (war 0x21, A1=HIGH)
    - 0x23: Top Board Buttons(war 0x22, A1=HIGH, A0=HIGH)
    pin_config.h: RelayPinDef vereinfacht (mcpIndex entfernt,
    gleiche Pinnummer auf SET- und RESET-MCP), RELAY_PULSE_MS=15ms,
    Relay-Typ DSP1A-L2-DC12V vollständig dokumentiert.
    main.cpp: MCP_ADDR_1/2 → MCP_ADDR_SET/RESET,
    setRelay() und startup-Reset angepasst.
    [main.cpp, pin_config.h]
2026-03-02 Base-Board bistabile Relais +Feritte plaziert
    [HS-IO Baseboard.PrjPcb, HS-IO ESP32.SchDoc, HS-IO Outputs.SchDoc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]
2026-03-02 Design-Rule 2mm innerhalb 240V-Class und 4mm 240V zum Rest
    [HS-IO-BaseBoard.PcbDoc]
2026-03-15 feat: OLED-Display + Kanalnamen + Button-Navigation
    Firmware:
    - display.h/cpp: Adafruit SSD1306 128x64, namespace display::
    Layout: Kanal#/Name | EIN/AUS (2x) | Restzeit | Hint-Zeile
    - main.cpp: channelNames[12], displayChannel, tempTimeAdjustMs[12]
    - UP/DOWN scrollt Kanaele; ENTER togglet; LEFT/RIGHT +/-1min Restzeit
    - getRemainingAutoOffSeconds() beruecksichtigt tempTimeAdjustMs
    - setRelay() resettet tempTimeAdjustMs, ruft updateDisplay()
    - loadConfig()/NVS: Keys name0-name11 (Default "Ausgang N")
    - WebSocket: neuer Command 'name', State-JSON enthaelt 'names'-Array
    - I2C Bus Recovery + Wire.setTimeOut(10ms)
    - RESET_PERIPHERIE_PIN (GPIO2) in setup() initialisiert
    - OLED_HA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
    [HS-IO Baseboard.PrjPcb, HS-IO ESP32.SchDoc, HS-IO Inputs.SchDoc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]
2026-03-15 wip: PCB Base- und Top-Board in Arbeit
    [HS-IO ESP32.SchDoc, HS-IO TopBoard.PcbDoc, HS-IO-BaseBoard.PcbDoc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]
2026-03-20 Layout fertig
    [HS-IO Inputs.SchDoc, HS-IO TopBoard.PcbDoc, HS-IO-BaseBoard.PcbDoc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]
2026-03-21 V1.0 Layout fertig
    [HS-IO Baseboard.PrjPcb, HS-IO TopBoard.PcbDoc, HS-IO Topboard.PrjPcb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]
2026-03-22 Widerstände an den Eingängen von 560 auf 1k5 erhöht
    [HS-IO ESP32.SchDoc, HS-IO-BaseBoard.PcbDoc]
2026-03-22 Label angepasst
    [HS-IO-BaseBoard.PcbDoc]
2026-03-28 PCB-Stand: Schaltplan, Top Board PCB, OLED 3D-Modell, LTspice Doku
    - HS-IO-Top.SchDoc aktualisiert
    - HS-IO TopBoard.PcbDoc aktualisiert
    - OLED-Disp.step 3D-Modell hinzugefügt
    - LTspice Simulationen Eingangstufe (8VAC, realistisch, Optokoppler) hinzugefügt
    - Top Board Projektstruktur (PrjPcbStructure) hinzugefügt
    [HS-IO TopBoard.PcbDoc, HS-IO-Top.SchDoc, OLED-Disp.step]
2026-03-28 Top Board PCB aktualisiert
    [HS-IO TopBoard.PcbDoc]
2026-03-28 Topboars commmit-id angepasst
    [HS-IO TopBoard.PcbDoc, HS-IO Topboard.PrjPcb]
2026-03-29 Taster versetzt
    [HS-IO ESP32.SchDoc, HS-IO Inputs.SchDoc, HS-IO TopBoard.PcbDoc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]
2026-03-29 Net Antenna auf Topboard entfernt
    [HS-IO TopBoard.PcbDoc]
2026-03-29 LP-Überarbeitung: Base Board + Top Board PCB, Schaltplan, 3D-Modelle
    - HS-IO-BaseBoard.PcbDoc aktualisiert
    - HS-IO TopBoard.step 3D-Modell hinzugefügt
    - OutJob-Dateien für Base Board und Top Board hinzugefügt
    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
    [HS-IO TopBoard.PcbDoc, HS-IO TopBoard.step, HS-IO-BaseBoard.PcbDoc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]
2026-03-29 LP-Überarbeitung: BaseBoard PCB, Schaltplan Outputs, Projektdateien
    [HS-IO Baseboard.PrjPcb, HS-IO Outputs.SchDoc, HS-IO Topboard.PrjPcb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]
2026-03-29 LP-Überarbeitet
    [HS-IO TopBoard.PcbDoc, HS-IO-BaseBoard.PcbDoc]
2026-04-10 Baseboard V1.1: Plane 3.3V ging über Relais!!!
    [HS-IO Baseboard.PrjPcb, HS-IO ESP32.SchDoc, HS-IO Inputs.SchDoc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]
2026-04-12 BaseBoard: Optokoppler korrekt orientiert, ESP32 um 180° gedreht
    - ILD213T (V200-V205) neu eingefügt ohne Spiegelung (LEDs korrekt gepolt)
    - ESP32-S3 (U100) um 180° gedreht: USB-Anschluss von P101 weg zugänglich
    [HS-IO ESP32.SchDoc, HS-IO Inputs.SchDoc, HS-IO-BaseBoard.PcbDoc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]
2026-04-12 LT-Spice files geändert PrjPcb geändert
    [HS-IO Baseboard.PrjPcb, HS-IO Topboard.PrjPcb]
2026-04-12 ESP32 Footprint geändert
    [HS-IO Inputs.SchDoc]
2026-04-12 Abstand zm ESP-Vergrößert. Iso-Abstand zu Inputs vergrößert
    [HS-IO ESP32.SchDoc, HS-IO-BaseBoard.PcbDoc]
2026-04-12 Beschriftung abgepasst
    [HS-IO-BaseBoard.PcbDoc]
2026-04-19 Firmware v1.1.0: Web-OTA, Timer-Buttons, Auto-Repeat
    - ElegantOTA fuer Firmware- und LittleFS-Update via Browser (/update)
    - Tasten UP/DOWN: Kanalnavigation, LEFT/RIGHT: Timer-Anpassung mit variablen Schrittweiten
    - Auto-Repeat fuer LEFT/RIGHT: nach 600ms Halten alle 150ms wiederholen
    - Timer-Standard 24h bei erstem Tastendruck ohne konfigurierten Timer
    - Webseite zeigt Firmware-Version und WiFi-Passwort vorausgefuellt
    - ArduinoOTA (espota) fuer IDE/CLI-Upload behalten
    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
2026-04-20 RUN-LED Blinker, DC-Eingang 1x Drücken, Versionsanzeige fixes
    - RUN-LED blinkt alle 2s (250ms-Tick im Loop)
    - S0-Eingang DC-Modus: 2 Flanken (1x Drücken+Loslassen) statt 4
    - Version wird vor dem Build hochgezählt (nicht nach), damit Display-Version stimmt
    - OLED: 12-Kanal-Statusleiste, Boot-Screen zeigt Firmware-Version
    - bump_version.py: direkt beim Script-Laden statt als PreAction-Callback
    [main.cpp]
2026-04-23 fix: MCP23017 SET/RESET-Adressen vertauscht + Impulsdauer erhöht
    Problem:
    Die MCP23017-Adressen für SET- und RESET-Spulen waren in der Firmware
    invertiert. MCP_ADDR_SET war auf 0x20 und MCP_ADDR_RESET auf 0x21
    konfiguriert, auf der Platine sind die Spulen jedoch genau umgekehrt
    verdrahtet. Das führte dazu, dass beim Einschalten eines Relais der
    RESET-Impuls gesendet wurde und umgekehrt — die Relais schalteten in
    die falsche Richtung.
    Diagnose:
    - Oszi-Messung bestätigte: Impulse (12V→0V→12V) kommen korrekt an
    beiden Spulen des Relais an
    - Spulenwiderstand 470 Ω gemessen (Spec: 480 Ω) → Spule intakt
    - Direktes Anlegen von 12V an SET/RESET schaltet das Relais korrekt
    - Ursache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
    [pin_config.h]
2026-04-24 docs: Kommentare für MCP23017 SET/RESET-Adressen korrigiert
    [pin_config.h]
2026-04-24 fix: DC-Input Timeout, rollover-sicherer Freeze-Vergleich, Timer-Clamp
    1. DC-Eingang: Timeout in DET_COUNTING (2000 ms)
    - Blieb die Rückflanke aus (dauerhaft anliegendes Signal), hing der
    Kanal in DET_COUNTING bis zur nächsten Flanke und blockierte.
    - Fix: Bei DC-Modus nach 2 s ohne weitere Flanke → Reset nach IDLE,
    inputState = false. Kanal ist danach sofort wieder reaktionsfähig.
    2. Rollover-sicherer Freeze-Vergleich
    - 'now >= timerFreezeExpiry[i]' liefert nach millis()-Überlauf
    (~49,7 Tage) falsche Ergebnisse, da unsigned Vergleich dann
    in die falsche Richtung kippt.
    - Fix: '(long)(now - timerFreezeExpiry[i]) >= 0' nutzt vorzeichenbehaftete
    Subt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
    [main.cpp]
2026-04-24 feat: Passwort-Reset per ENTER-Taste beim Boot, IP-Anzeige beim Start
    Passwort-Reset (Credential-Recovery):
    - ENTER-Taste beim Einschalten gedrückt halten startet einen
    5-Sekunden-Countdown auf dem OLED-Display
    - Wird ENTER die vollen 5 Sekunden gehalten, werden Web-Benutzer
    und Web-Passwort auf 'admin'/'admin' zurückgesetzt und in NVS
    gespeichert; danach normaler Boot
    - Loslassen während des Countdowns bricht den Reset ab
    - Bestätigung wird 2 Sekunden auf dem Display angezeigt
    IP-Anzeige beim Start:
    - Nach abgeschlossenem Setup werden AP- und STA-IP-Adresse
    3 Sekunden lang auf dem OLED angezeigt
    - STA zeigt 'nicht verbunden' wenn keine WLAN-Verbindung besteht
    Neue Display-Funk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
    [main.cpp]
2026-04-24 fix/refactor: 5 Sicherheits- und Robustheitsprobleme behoben
    1. WiFi-Passwort bleibt bei leerem Feld erhalten (hoch)
    - Client sendet 'pass' jetzt nur wenn das Feld ausgefüllt ist
    - Server übernimmt sta_pass nur wenn der empfangene Wert nicht leer ist
    - Vorher wurde sta_pass auf "" gesetzt wenn das Feld leer blieb,
    was die WLAN-Verbindung beim nächsten Start kaputtmachte
    2. MCP-Kommentar und Log-Namen korrigiert (mittel)
    - setupMCP(): Kommentar und names[] zeigten noch 0x20=SET / 0x21=RESET
    - Korrigiert auf tatsächliche Verdrahtung: 0x21=SET / 0x20=RESET
    3. Negative Timer-Werte abgefangen (mittel)
    - secs: -1 wurde als uint32_t zu 0xFFFFFFFF und dann auf 86400 gekl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
    [main.cpp]
2026-04-24 fix: OTA-Passwort entkoppelt, Inline-Kommentar, schwache Defaults dokumentiert
    1. OTA-Passwort (ota_pass) als eigener NVS-Key entkoppelt von ui_pass
    - Eigene Variable/NVS-Key 'ota_pass' (Standard: admin)
    - Änderbar über Web-UI (neues Feld 'OTA-Passwort') und wifi-Command
    - Klarer Hinweis im UI dass platformio.ini --auth manuell angepasst
    werden muss wenn das OTA-Passwort geändert wird
    2. Inline-Kommentar in platformio.ini korrigiert
    - Kommentar hinter --auth=admin in eigene Zeile verschoben um
    Parser-Probleme mit dem Argument zu vermeiden
    3. Schwache Default-Credentials dokumentiert
    - AP_PASS, ui_user/ui_pass und ota_pass mit Hinweis-Kommentar
    versehen (Sta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
    [main.cpp]
2026-04-24 feat: Netzwerk-Hostname HS-IO, Timer hh:mm:ss, Bugfixes
    === Neue Features ===
    Netzwerk-Hostname "HS-IO":
    - WiFi.setHostname("HS-IO") vor WiFi.begin() -> DHCP-Eintrag im Router
    - MDNS.begin("HS-IO") -> Gerät erreichbar als http://hs-io.local (Port 80 advertised)
    - ArduinoOTA.setHostname("HS-IO") konsistent
    Web-UI Timer-Eingabe hh:mm:ss:
    - Eingabefeld zeigt und akzeptiert hh:mm:ss statt Sekunden
    - Flexibler Parser: "7200"=2h, "30m", "30:00"=30min, "4h", "1h30m", "1:30:00"
    - Pfeiltaste hoch/runter: ±10 Minuten direkt im Feld
    - Klick ins Feld: gesamter Text wird markiert
    - Rest-Anzeige ebenfalls in hh:mm:ss
    Button-Startwerte (kein Timer aktiv):
    - Erster LEFT-Druck: 1h
    - Erster RIGHT-Druck: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
    [main.cpp, pin_config.h]
2026-04-26 feat: Eingangs-Namen, zwei-seitige Web-UI, LED-Anzeige, Bugfixes
    Web-UI:
    - Hauptseite (index.html) zeigt nur Kanal-Zuordnung & Status
    - Eingangs-Namen als Label, Ausgangs-Namen in Dropdown ("A1: Name")
    - LED-Anzeige für Eingang (orange) und Ausgang/Relais (grün) sichtbar
    - Timer-Eingabe hh:mm:ss, Pfeiltasten ±10 min, Klick markiert alles
    - Auto-Aus bis 1 Woche, adaptive Schritte (1m/5m/10m/30m/1h/6h)
    - Erster Pfeil-Links = 1h, Erster Pfeil-Rechts = 6h
    - UI-Version angezeigt (UI v1.1)
    - Konfigurationsseite (config.html) neu:
    - Eingangs- und Ausgangs-Namen editierbar (max. 60 Zeichen)
    - WiFi / Web-Credentials / OTA-Passwort konfigurierbar
    - Nr.-Spalte auf minimale Breite g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
    [main.cpp, pin_config.h]
2026-04-26 fix: WebSocket-Robustheit, wss://-Unterstützung, Dropdown-Optimierung
    - wsSend()-Hilfsfunktion: prüft readyState vor jedem WS-Send (verhindert
    JS-Fehler bei Klick während Reconnect)
    - WebSocket-URL: ws:// -> dynamisch wss:// bei HTTPS (beide Seiten)
    - JSON.parse in ws.onmessage: try/catch gegen defekte Frames
    - fetch /api/state: .catch() gegen Netzwerkfehler / Auth-Fehler
    - updateDropdownLabels(): nur noch bei Namensänderung (applyState),
    nicht mehr bei jedem sekündlichen updateUI()
    - UI v1.2
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2026-04-27 fix: Zugangsdaten ohne Neustart ändern, WLAN-PW im Klartext, SSID-Überschreib-Bug
    - Web-Zugangsdaten (Benutzer/Passwort) und OTA-Passwort haben eigene
    Speichern-Buttons ohne Neustart; applyWebAuth() aktualisiert alle
    Handler live
    - WLAN-Sektion nur noch für SSID/Passwort; Firmware-Update-Button in
    Konfiguration sichern-Sektion verschoben
    - SSID wird nicht mehr überschrieben wenn Feld leer ist (sta_ssid nur
    bei length > 0 aktualisiert)
    - WLAN-Passwort wird im Klartext angezeigt und aus /api/state befüllt
    - Neue WS-Kommandos: set_web_creds, set_ota_pass
    [main.cpp]
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2026-05-01 refactor: Eingangserkennung auf einheitliche Press-State-Machine umgestellt
    Alte 4-Zustands-Statemachine (DET_IDLE/DETECTING/COUNTING/LOCKED) durch
    einheitliche Logik ersetzt, die DC- und 8VAC-Signale identisch behandelt:
    - signalActive = raw || letzte Flanke < 30ms (unifiziert AC+DC)
    - Steigende Flanke: pressStartMs merken, Taster-Ausgänge EIN
    - Langdruck ≥2s: alle Ausgänge AUS (funktioniert jetzt auch für AC)
    - Fallende Flanke ohne Langdruck: Toggle-OR-Logik bzw. Taster-Ausgänge AUS
    Fixes: AC-Langdruck, Bounce-als-AC-Fehlerkennung, fehlendes Langdruck im Taster-Modus
    [main.cpp]
2026-05-01 fix: Langdruck-Alloff mit saveTimerAdjust=true wie normaler alloff-Pfad
    [main.cpp]
2026-05-01 fix: Eingangs-LED-Polarität und Startup-Schein-Flanke beheben
    GPIO ist aktiv-LOW (Schmitt-Inverter invertiert Optokoppler-Ausgang):
    - signalActive auf !raw umgestellt (HIGH=inaktiv, LOW=aktiv)
    - setupInputPins(): inputLastEdgeMs mit now-200 initialisieren damit
    Holdoff-Fenster ab erstem loop() bereits abgelaufen ist
    - signalActivePrev mit !r vorbelegen → kein Schein-Trigger beim Start
    [main.cpp]
2026-05-01 feat: Taster-/Toggle-Modus für Ein- und Ausgänge, Langdruck, Polaritätsfix (v1.3.12)
    ## Eingangserkennung – komplette Überarbeitung (main.cpp)
    Die bisherige 4-Zustands-Statemachine (DET_IDLE → DET_DETECTING → DET_COUNTING →
    DET_LOCKED) wurde durch eine einheitliche Press-State-Machine ersetzt, die DC-
    Trockenkontakte und 8VAC-Signale identisch behandelt:
    signalActive = !raw || (nowIn - inputLastEdgeMs < 30 ms)
    - !raw: GPIO ist aktiv-LOW – der SN74HCT14-Schmitt-Inverter kehrt den
    Optokoppler-Ausgang um; im Leerlauf liegt GPIO HIGH an.
    - 30 ms: überbrückt die Lücke zwischen 8VAC-Halbwellen (50 Hz = 20 ms/Zyklus).
    Bugs der alten Statemachine, die damit beh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
    [main.cpp]
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2026-05-01 fix: Null-Guard in updateUI/updateRemaining, Namen direkt in rebuildOutputTable
    updateUI() und updateRemaining() greifen ohne Guard auf out-*-Elemente zu.
    Deaktivierte Ausgänge fehlen im DOM → TypeError → Loop bricht ab → alle
    folgenden Kanäle (z.B. A8) erhalten keine Namens-Aktualisierung mehr.
    - updateUI(): out-led/out-name/out-time nur setzen wenn Element existiert
    - updateRemaining(): out-rest nur setzen wenn Element existiert
    - rebuildOutputTable(): Zell-Inhalt direkt mit state.names[i] befüllen statt
    Platzhalter "Ausgang X" (der erst durch updateUI() überschrieben werden muss)
2026-05-03 feat: OLED-Umlautkorrektur und Marquee-Scroll für Kanalnamen (v1.3.22)
    ## Umlaut-Fix (UTF-8 → CP437)
    Die Web-UI sendet Kanalnamen als UTF-8 (z.B. 'ä' = 0xC3 0xA4). Der
    Adafruit-GFX-Treiber nutzt intern CP437, wo Umlaute an anderen
    Positionen liegen (z.B. 'ä' = 0x84). Bisher wurden die zwei UTF-8-Bytes
    als zwei separate, falsche Zeichen dargestellt.
    Neue Hilfsfunktion utf8ToDisplay() in display.cpp wandelt alle deutschen
    Umlaute und ß korrekt um:
    ä (C3 A4) → 0x84 ö (C3 B6) → 0x94 ü (C3 BC) → 0x81
    Ä (C3 84) → 0x8E Ö (C3 96) → 0x99 Ü (C3 9C) → 0x9A
    ß (C3 9F) → 0xE1
    Die Positionen wurden durch Analyse der tatsächlich installierten
    glcdfont.c in .pio/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
    [main.cpp]
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2026-05-03 Web-App: Lauftext und Smartphone-Header korrigieren
    Die Startseite misst lange Ausgangsnamen jetzt anhand der tatsächlich gerenderten Breite statt nur über scrollWidth/clientWidth. Dadurch wird der Lauftext erst aktiviert, wenn der Text den verfügbaren Bereich wirklich überschreitet. Zusätzliche Neuberechnungen nach Fensteränderungen, Seitenladeabschluss und dem initialen Zustandsabruf verhindern falsche Messwerte während des frühen Layouts.
    Der Verbindungsstatus im Header ist auf kleinen Smartphone-Displays nicht mehr rechtsbündig an der Displaykante positioniert. Er nutzt den verfügbaren Headerbereich mit sauberem Überlaufverhalten, damit der Text Verbunden nicht mehr vom Brows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
2026-08-10 feat: Ausgaenge von "Alles aus" ausnehmbar, WLAN-AP-Auswahl (v1.3.61)
    Alles-Aus-Ausnahme pro Ausgang:
    - Neues Flag outAllOffEnabled[] (NVS-Key aoff<i>, Default 1 = mitschalten)
    - Sammelabschaltung zentral in allOutputsOff(); ersetzt zwei getrennte
    Schleifen und gilt damit fuer alle Ausloeser: Eingangs-Langdruck (2s),
    Web-UI und App. reset_io schaltet weiterhin bewusst alles ab.
    - WebSocket-Kommando set_out_alloff, Feld out_alloff in beiden
    State-Buildern, Spalte "Alles aus" in config.html inkl. Export/Import
    WLAN: staerksten AP waehlen statt erstgefundenen
    - setScanMethod(WIFI_ALL_CHANNEL_SCAN) + setSortMethod(WIFI_CONNECT_AP_BY_SIGNAL)
    vor WiFi.begin(). Mit WIFI_FAST_SCAN landete d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
    [main.cpp]
